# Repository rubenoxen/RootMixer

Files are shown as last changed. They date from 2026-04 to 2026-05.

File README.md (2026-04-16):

<p align="center">
  
  
  
  
</p>

# RootMixer 

A modular, bare-metal USB MIDI controller designed from scratch. Built around the STM32F411 (ARM Cortex-M4) using pure C CMSIS registers, featuring an expandable I2C and Analog Multiplexing architecture.

<p align="center">
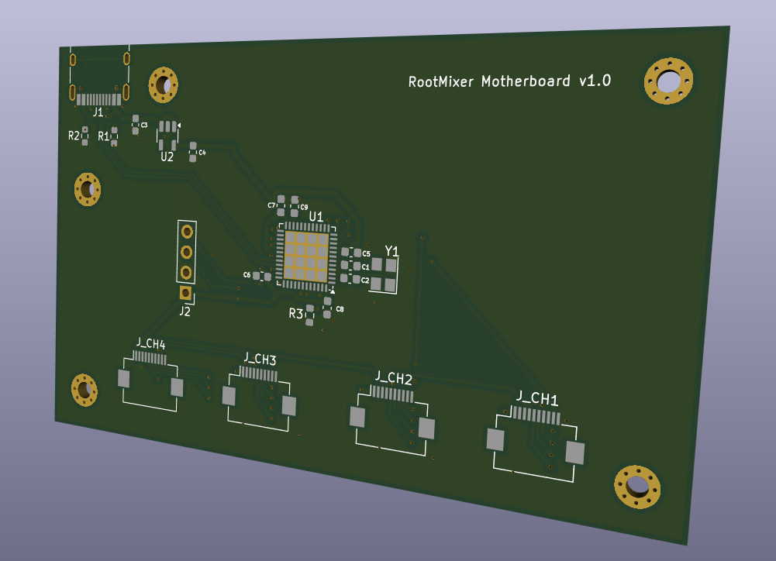
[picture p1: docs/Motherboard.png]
RootMixer 3D Render
  
</p>

##  Features
* **Bare-Metal Firmware:** Zero heavy libraries (No HAL, No Arduino). Direct register manipulation for ultra-low latency (<2ms scan rate).
* **Hardware Multiplexing:** Daisy-chained `CD74HC4067` multiplexers allowing up to 16 analog channels per ADC pin.
* **Modular Design:** 1 Motherboard supports up to 4 swappable Channel Strips.
* **Native USB MIDI:** Implemented custom USB Device stack to interface natively with DAWs (Ableton, FL Studio) without drivers.
* **Real-time OSless Scheduler:** Custom `SysTick` non-blocking architecture.

##  Project Structure
* `/firmware`: Pure C source code, Makefile, and linker scripts.
* `/hardware`: KiCad 7 projects, Schematics (PDF), and Gerber files ready for JLCPCB.
    * `/Motherboard`: Main STM32 brain, LDO power supply, and Expansion ports.
    * `/Daughterboard_Channel`: The swappable channel strip (1x SC6021N Fader, 4x WH148 Pots, Mute Button).

##  Build & Flash (Firmware)
Requires `arm-none-eabi-gcc`, `make`, and `openocd`.

```bash
cd firmware
make clean
make
make flash
```

## License
This project is licensed under the MIT License - see the LICENSE file for details.

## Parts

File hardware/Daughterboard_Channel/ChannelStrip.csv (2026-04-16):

Source: | /home/ruben/Workspace/RootMixer/hardware/Daughterboard_Channel/ChannelStrip/ChannelStrip.kicad_sch
Date: | jue 16 abr 2026 21:29:24
Tool: | Eeschema 7.0.11+dfsg-1build4
Generator: | /usr/share/kicad/plugins/bom_csv_grouped_by_value_with_fp.py
Component Count: | 13
Ref | Qnty | Value | Cmp name | Footprint | Description | Vendor | DNP
FADER1 | 1 | POT1 | R_Potentiometer | Potentiometer_THT:Potentiometer_Bourns_PTA6043_Single_Slide | Potentiometer
H1 | 1 | MountingHole | MountingHole | MountingHole:MountingHole_2.2mm_M2_Pad_Via | Mounting Hole without connection
H2, H3, H4 | 3 | MountingHole_Pad | MountingHole | MountingHole:MountingHole_2.2mm_M2_Pad_Via | Mounting Hole without connection
J1 | 1 | Conn_01x10 | Conn_01x10 | Connector_PinHeader_2.54mm:PinHeader_1x10_P2.54mm_Vertical | Generic connector, single row, 01x10, script generated (kicad-library-utils/schlib/autogen/connector/)
POT1, POT2, POT3, POT4 | 4 | POT1 | R_Potentiometer | Potentiometer_THT:Potentiometer_Bourns_PTV09A-1_Single_Vertical | Potentiometer
R1 | 1 | 10k | R | Resistor_THT:R_Axial_DIN0207_L6.3mm_D2.5mm_P10.16mm_Horizontal | Resistor
SW1 | 1 | SW_Push | SW_Push | Button_Switch_THT:SW_PUSH_6mm | Push button switch, generic, two pins
U1 | 1 | CD74HC4067M | CD74HC4067M | Package_SO:SOIC-24W_7.5x15.4mm_P1.27mm | High-Speed CMOS Logic 16-Channel Analog Multiplexer/Demultiplexer, SOIC-24

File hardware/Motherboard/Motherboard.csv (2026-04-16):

Source: | /home/ruben/Workspace/RootMixer/hardware/Motherboard/Motherboard/Motherboard.kicad_sch
Date: | jue 16 abr 2026 21:26:49
Tool: | Eeschema 7.0.11+dfsg-1build4
Generator: | /usr/share/kicad/plugins/bom_csv_grouped_by_value_with_fp.py
Component Count: | 26
Ref | Qnty | Value | Cmp name | Footprint | Description | Vendor | DNP
C1, C2 | 2 | 12pF | C_Small | Capacitor_SMD:C_0603_1608Metric | Unpolarized capacitor, small symbol
C3, C4 | 2 | 1uF | C_Small | Capacitor_SMD:C_0603_1608Metric | Unpolarized capacitor, small symbol
C5, C6, C7, C8 | 4 | 100nF | C_Small | Capacitor_SMD:C_0603_1608Metric | Unpolarized capacitor, small symbol
C9 | 1 | 4.7uF | C_Small | Capacitor_SMD:C_0603_1608Metric | Unpolarized capacitor, small symbol
H1, H2, H3, H4, H5 | 5 | MountingHole | MountingHole | MountingHole:MountingHole_2.2mm_M2_Pad_Via | Mounting Hole without connection
J1 | 1 | USB_C_Receptacle_USB2.0_16P | USB_C_Receptacle_USB2.0_16P | Connector_USB:USB_C_Receptacle_HRO_TYPE-C-31-M-12 | USB 2.0-only 16P Type-C Receptacle connector
J2 | 1 | Conn_01x04 | Conn_01x04 | Connector_PinHeader_2.54mm:PinHeader_1x04_P2.54mm_Vertical | Generic connector, single row, 01x04, script generated (kicad-library-utils/schlib/autogen/connector/)
J_CH1, J_CH2, J_CH3, J_CH4 | 4 | Conn_01x10 | Conn_01x10 | Connector_FFC-FPC:Hirose_FH12-10S-0.5SH_1x10-1MP_P0.50mm_Horizontal | Generic connector, single row, 01x10, script generated (kicad-library-utils/schlib/autogen/connector/)
R1, R2 | 2 | 5.1k | R | Resistor_SMD:R_0603_1608Metric | Resistor
R3 | 1 | 10k | R | Resistor_SMD:R_0603_1608Metric | Resistor
U1 | 1 | STM32F411CEUx | STM32F411CEUx | Package_DFN_QFN:QFN-48-1EP_7x7mm_P0.5mm_EP5.6x5.6mm | STMicroelectronics Arm Cortex-M4 MCU, 512KB flash, 128KB RAM, 100 MHz, 1.7-3.6V, 36 GPIO, UFQFPN48
U2 | 1 | AP2112K-3.3 | AP2112K-3.3 | Package_TO_SOT_SMD:SOT-23-5 | 600mA low dropout linear regulator, with enable pin, 3.8V-6V input voltage range, 3.3V fixed positive output, SOT-23-5
Y1 | 1 | 25MHz | Crystal_GND24 | Crystal:Crystal_SMD_3225-4Pin_3.2x2.5mm | Four pin crystal, GND on pins 2 and 4

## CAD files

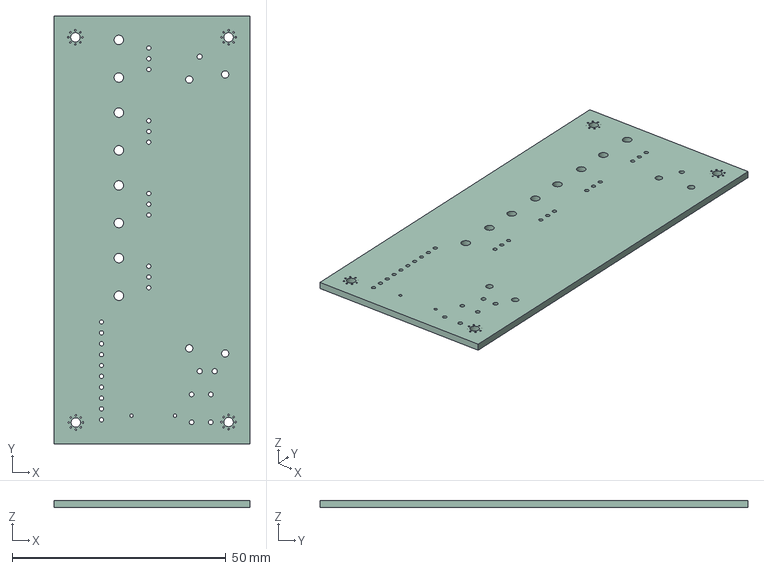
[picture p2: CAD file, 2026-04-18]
hardware/Daughterboard_Channel/ChannelStrip.step
45.8 x 100.0 x 1.60 mm

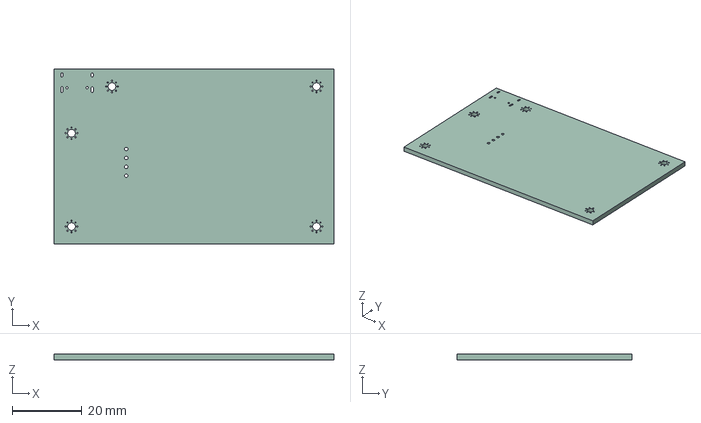
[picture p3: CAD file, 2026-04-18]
hardware/Motherboard/Motherboard.step
80.0 x 50.0 x 1.60 mm

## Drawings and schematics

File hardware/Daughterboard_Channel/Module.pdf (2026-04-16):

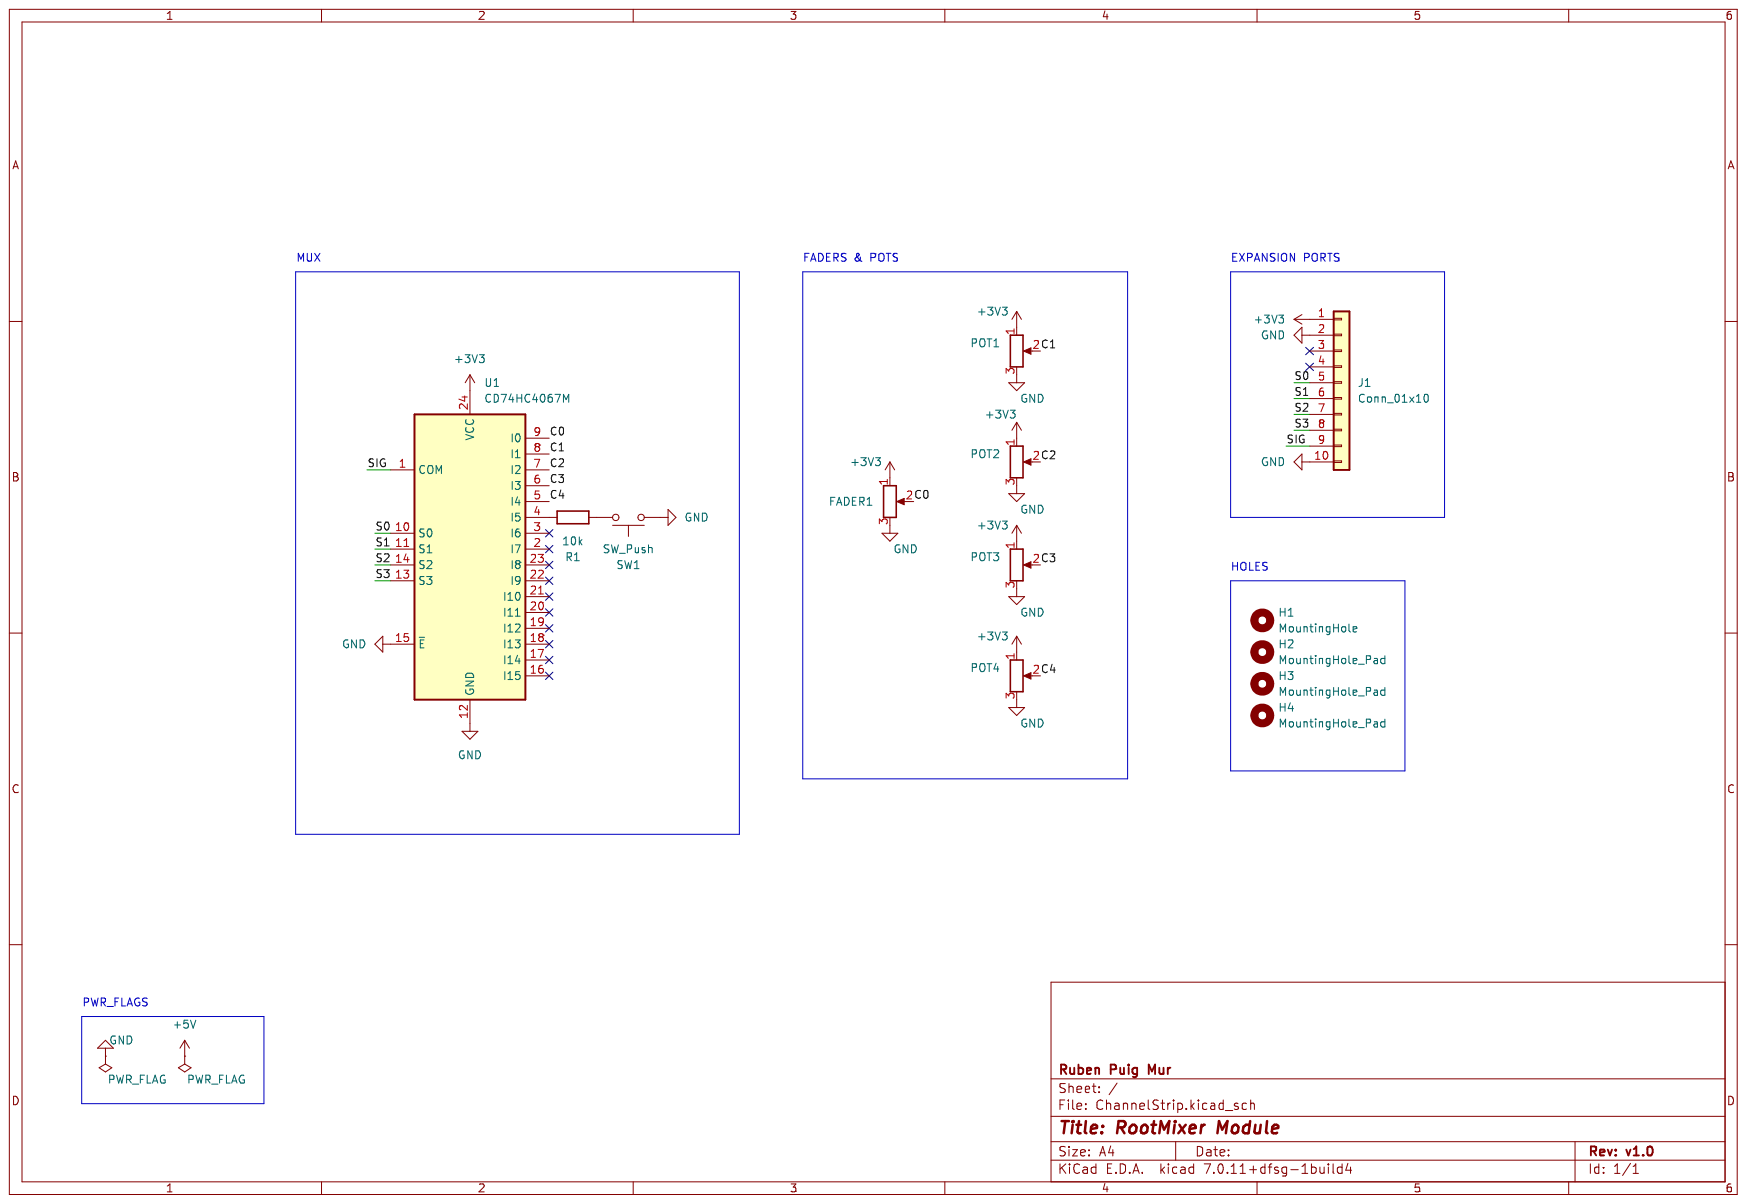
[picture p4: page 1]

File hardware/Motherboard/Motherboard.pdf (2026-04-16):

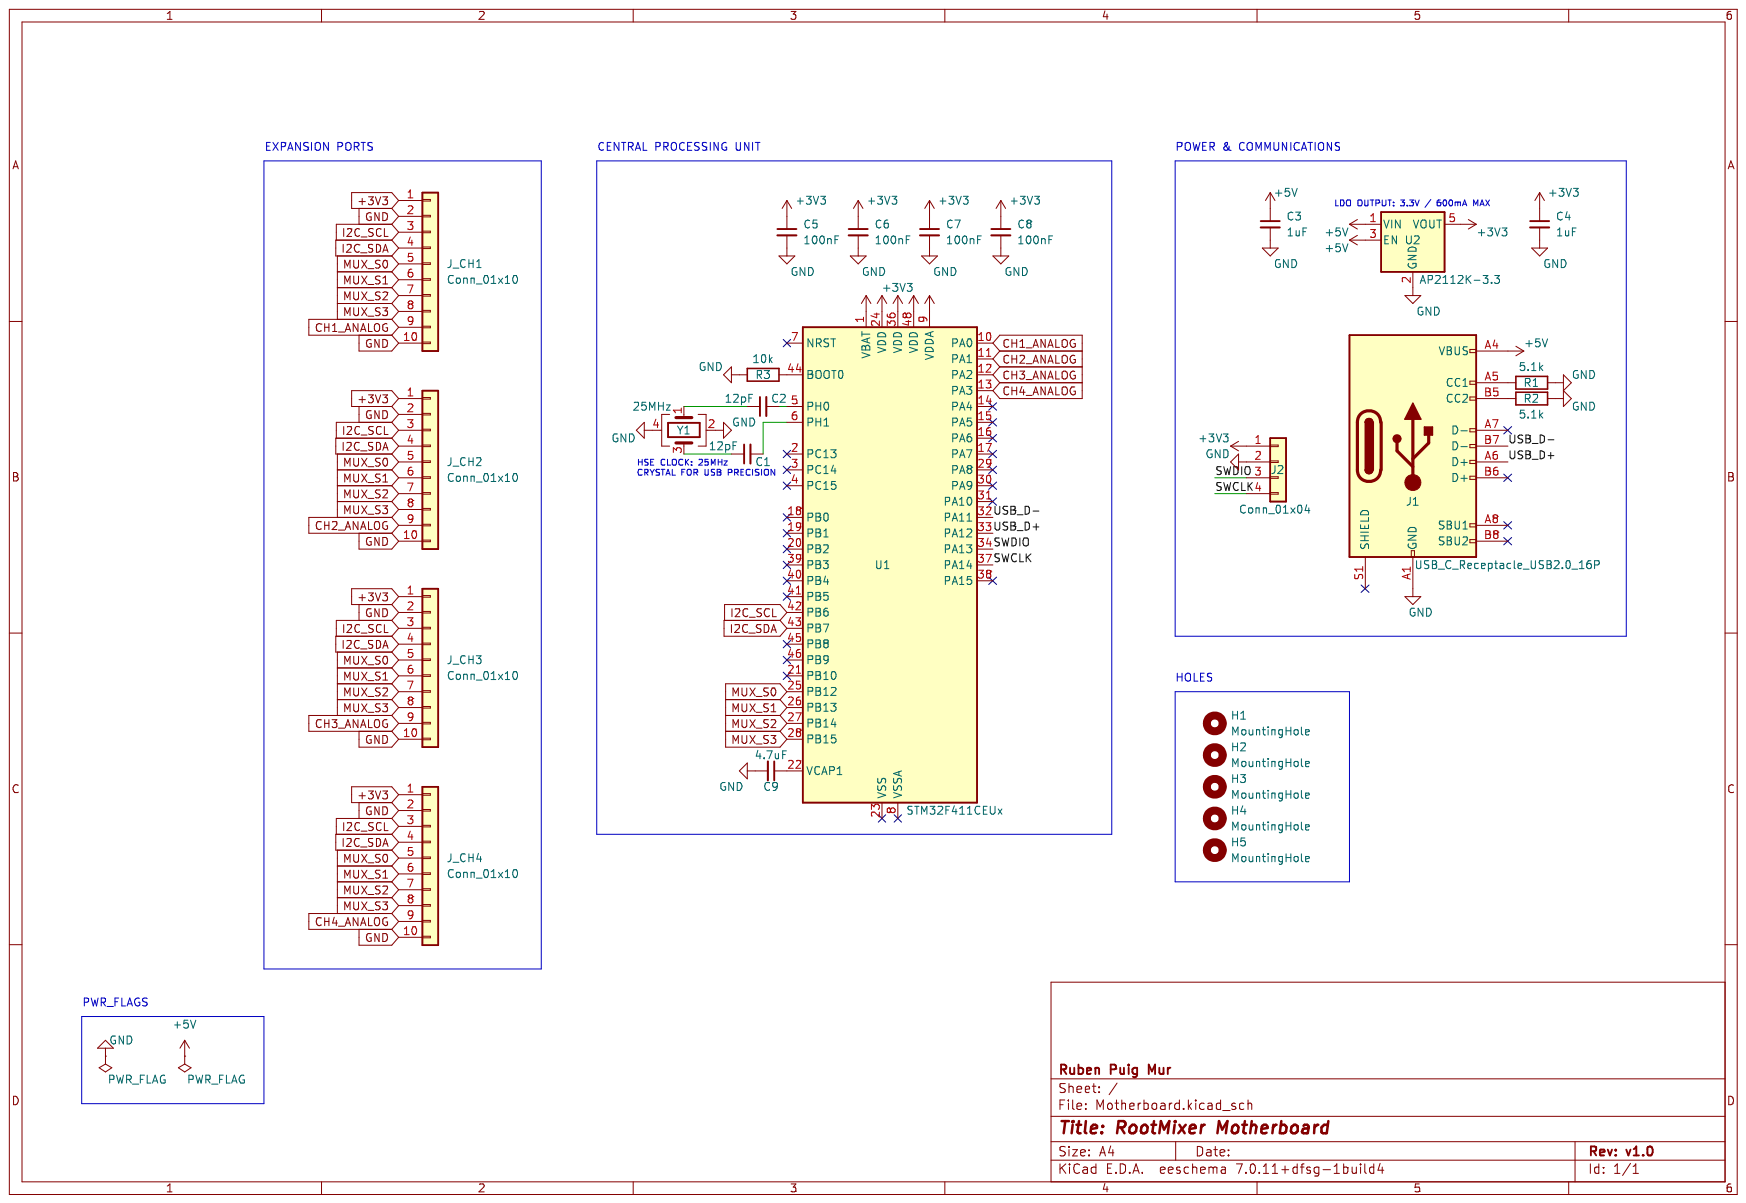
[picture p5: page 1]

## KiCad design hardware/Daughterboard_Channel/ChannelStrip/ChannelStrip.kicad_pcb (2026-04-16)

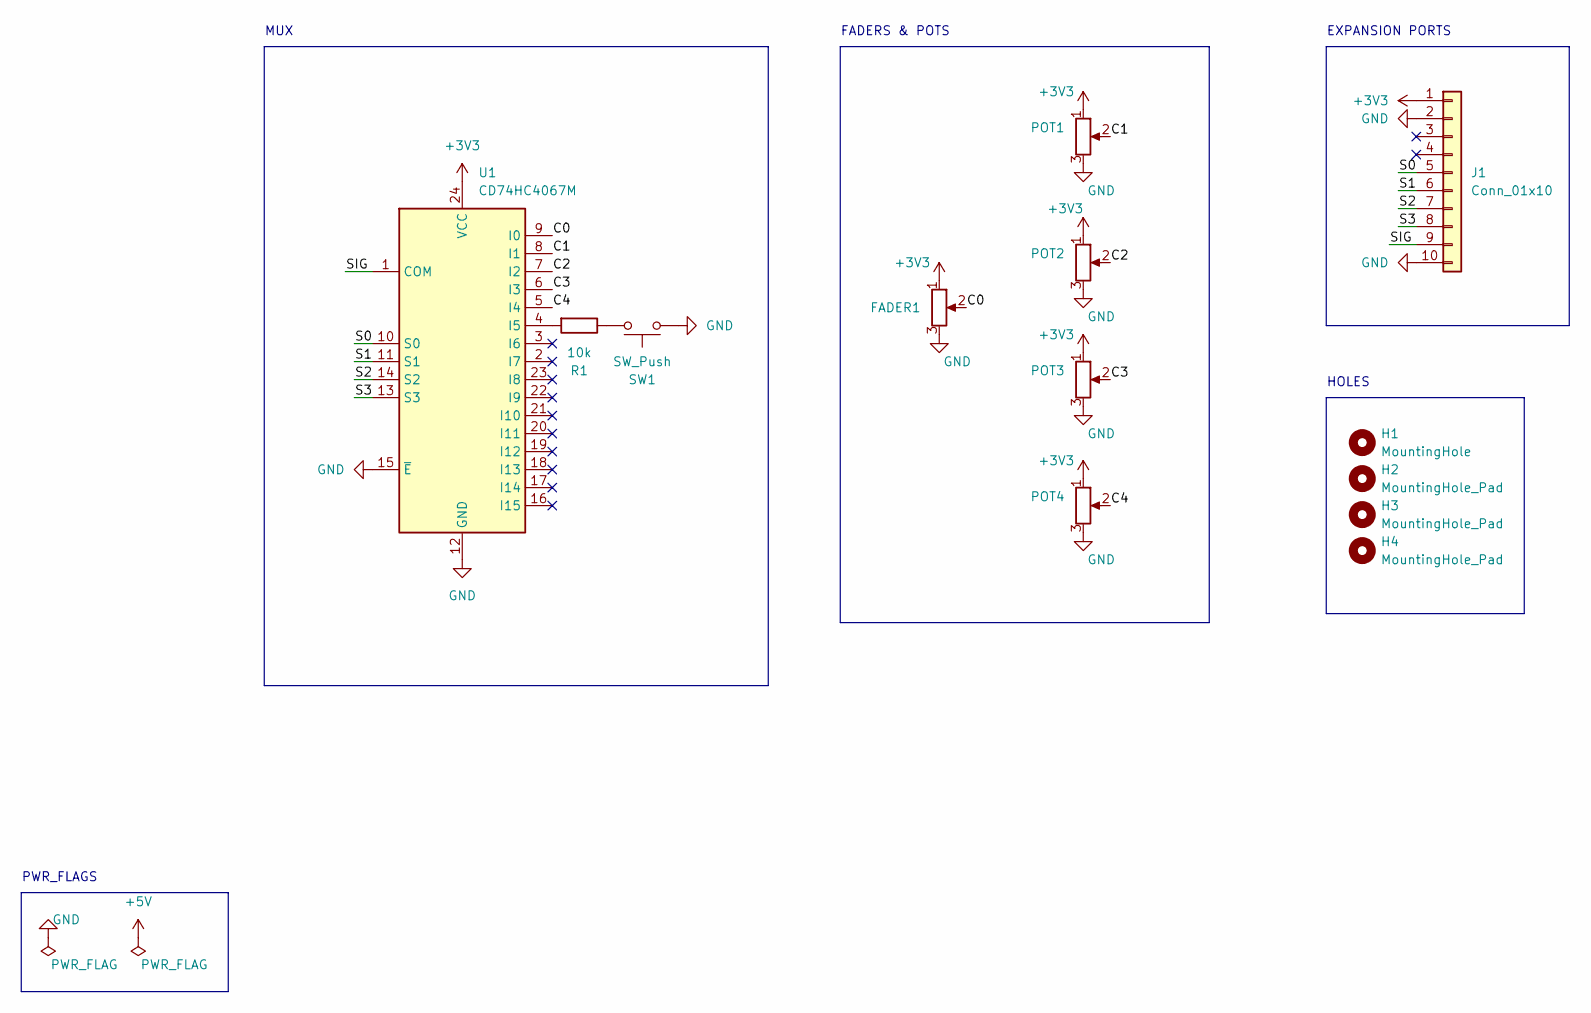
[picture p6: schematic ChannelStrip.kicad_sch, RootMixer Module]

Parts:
FADER1: POT1; Potentiometer_Bourns_PTA6043_Single_Slide
H1: MountingHole; MountingHole_2.2mm_M2_Pad_Via
H2, H3, H4: MountingHole_Pad; MountingHole_2.2mm_M2_Pad_Via
J1: Conn_01x10; PinHeader_1x10_P2.54mm_Vertical
POT1, POT2, POT3, POT4: POT1; Potentiometer_Bourns_PTV09A-1_Single_Vertical
R1: 10k; R_Axial_DIN0207_L6.3mm_D2.5mm_P10.16mm_Horizontal
SW1: SW_Push; SW_PUSH_6mm
U1: CD74HC4067M; SOIC-24W_7.5x15.4mm_P1.27mm

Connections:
+3V3: FADER1.1, J1.1, POT1.1, POT2.1, POT3.1, POT4.1, U1.24 (VCC)
/C0: FADER1.2, U1.9 (I0)
/C1: POT1.2, U1.8 (I1)
/C2: POT2.2, U1.7 (I2)
/C3: POT3.2, U1.6 (I3)
/C4: POT4.2, U1.5 (I4)
/S0: J1.5, U1.10 (S0)
/S1: J1.6, U1.11 (S1)
/S2: J1.7, U1.14 (S2)
/S3: J1.8, U1.13 (S3)
/SIG: J1.9, U1.1 (COM)
GND: FADER1.3, J1.2, J1.10, POT1.3, POT2.3, POT3.3, POT4.3, SW1.1, U1.12 (GND), U1.15 (~E)
unnamed: R1.1, SW1.2
unnamed: R1.2, U1.4 (I5)

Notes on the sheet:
FADERS & POTS
HOLES
PWR_FLAGS
EXPANSION PORTS
MUX

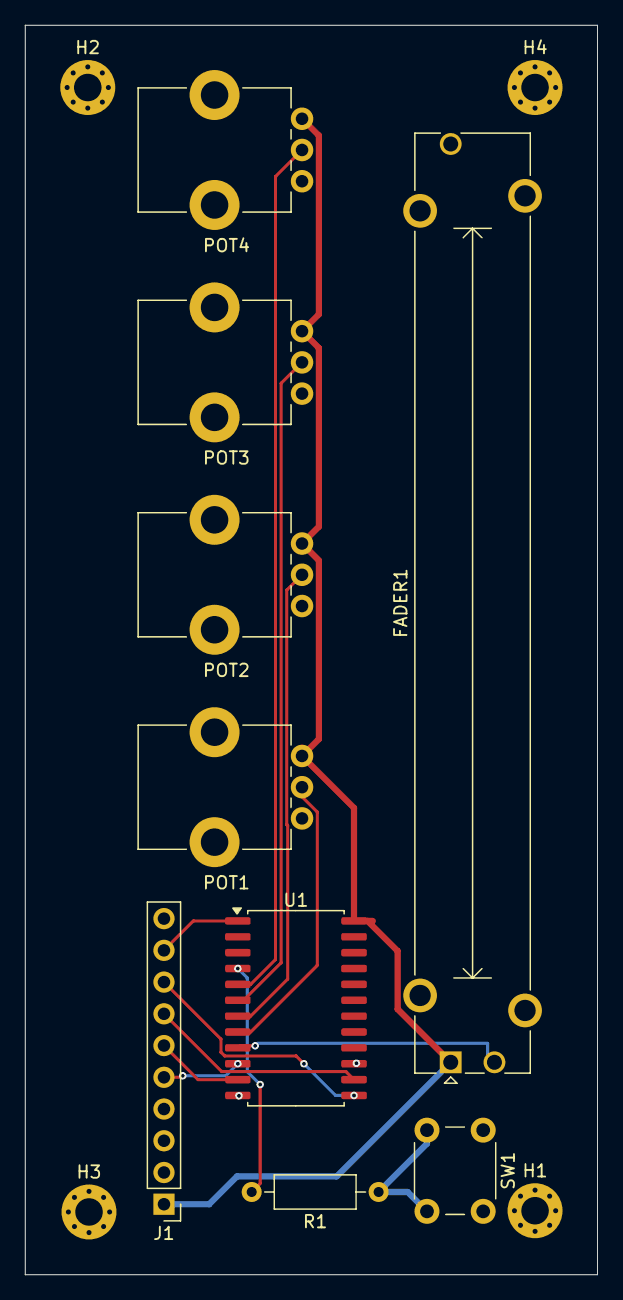
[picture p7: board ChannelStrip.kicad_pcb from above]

Board: 2 copper layers, 45.8 x 100.0 mm, 13 parts (0 on the bottom side), 14 nets.

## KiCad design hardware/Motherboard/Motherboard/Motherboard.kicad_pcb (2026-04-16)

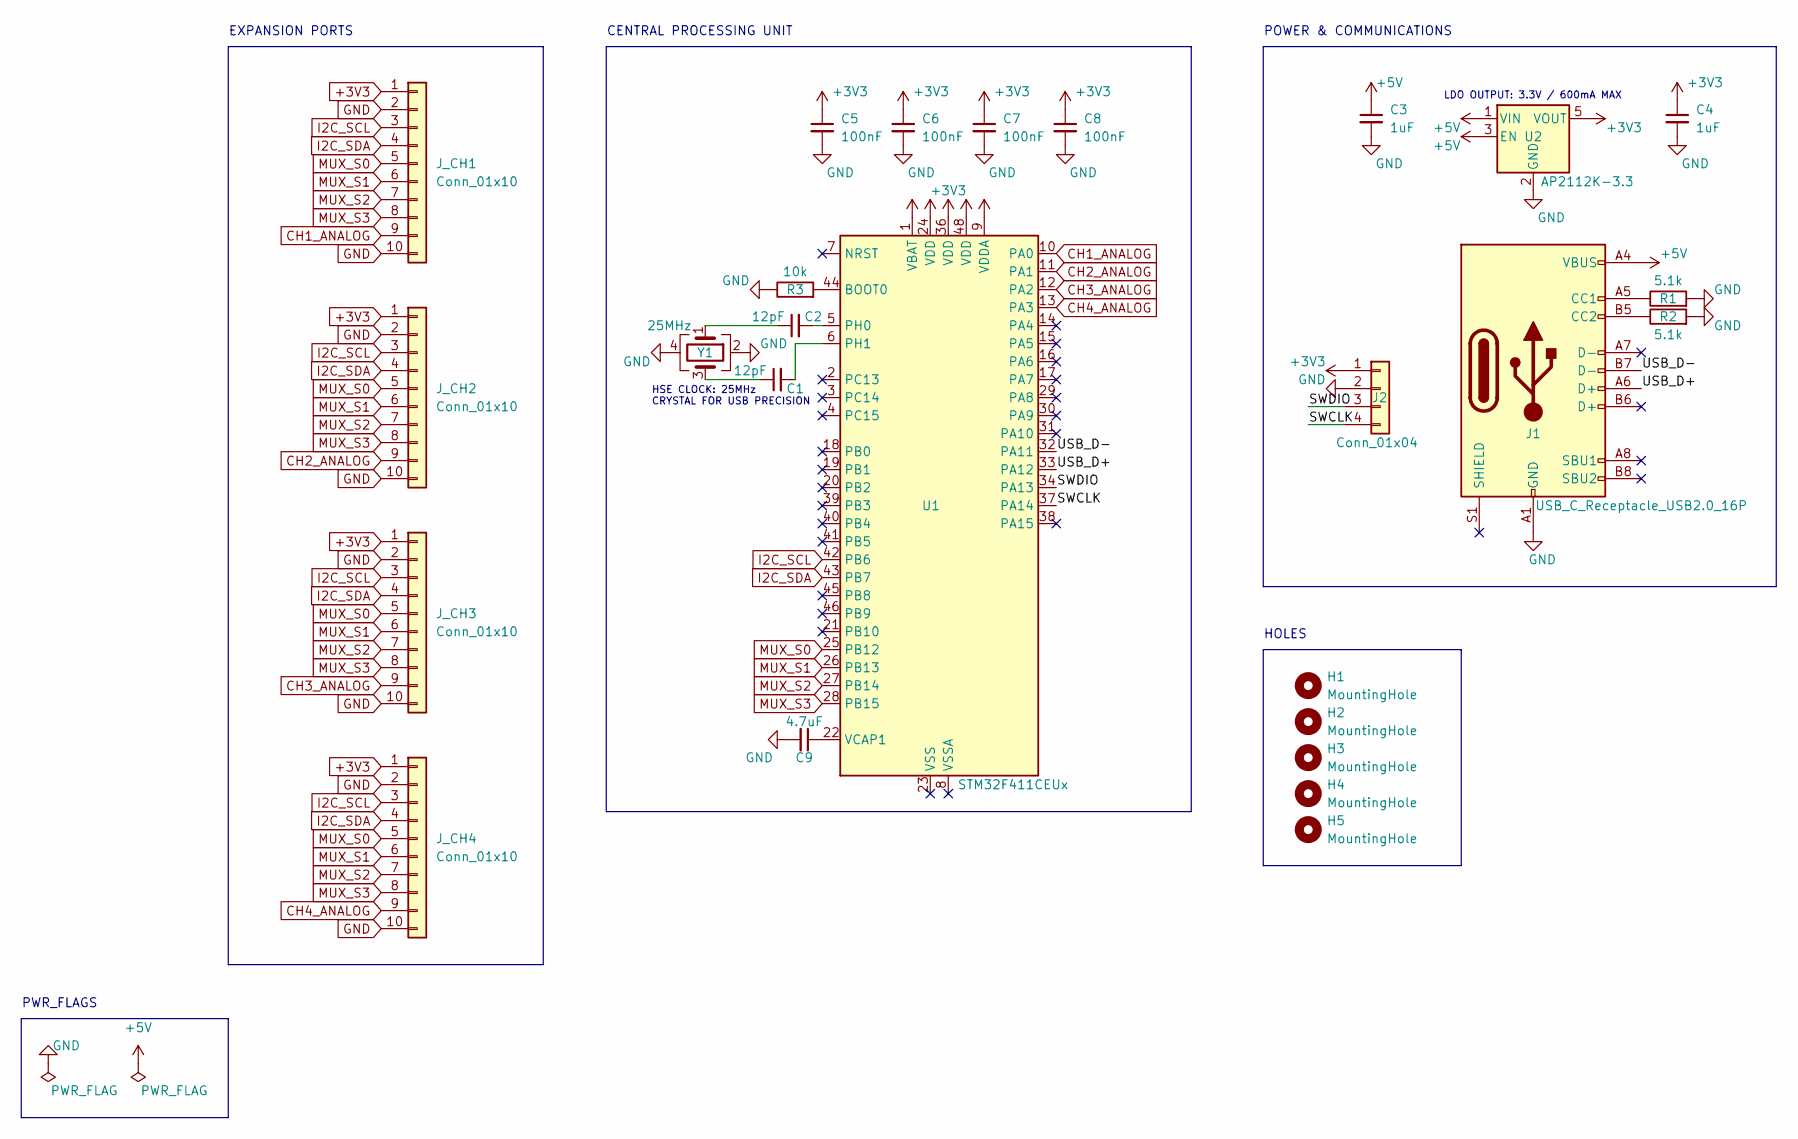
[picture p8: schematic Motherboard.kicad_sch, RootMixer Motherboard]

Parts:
C1, C2: 12pF; C_0603_1608Metric
C3, C4: 1uF; C_0603_1608Metric
C5, C6, C7, C8: 100nF; C_0603_1608Metric
C9: 4.7uF; C_0603_1608Metric
H1, H2, H3, H4, H5: MountingHole; MountingHole_2.2mm_M2_Pad_Via
J1: USB_C_Receptacle_USB2.0_16P; USB_C_Receptacle_HRO_TYPE-C-31-M-12
J2: Conn_01x04; PinHeader_1x04_P2.54mm_Vertical
J_CH1, J_CH2, J_CH3, J_CH4: Conn_01x10; Hirose_FH12-10S-0.5SH_1x10-1MP_P0.50mm_Horizontal
R1, R2: 5.1k; R_0603_1608Metric
R3: 10k; R_0603_1608Metric
U1: STM32F411CEUx; QFN-48-1EP_7x7mm_P0.5mm_EP5.6x5.6mm
U2: AP2112K-3.3; SOT-23-5
Y1: 25MHz; Crystal_SMD_3225-4Pin_3.2x2.5mm

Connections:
+3V3: C4.1, C5.1, C6.1, C7.1, C8.1, J2.1, J_CH1.1, J_CH2.1, J_CH3.1, J_CH4.1, U1.1 (VBAT), U1.9 (VDDA), U1.24 (VDD), U1.36 (VDD), U1.48 (VDD), U2.5 (VOUT)
+5V: C3.1, J1.A4 (VBUS), J1.A9 (VBUS), J1.B4 (VBUS), J1.B9 (VBUS), U2.1 (VIN), U2.3 (EN)
/SWCLK: J2.4, U1.37 (PA14)
/SWDIO: J2.3, U1.34 (PA13)
/USB_D+: J1.A6 (D+), U1.33 (PA12)
/USB_D-: J1.B7 (D-), U1.32 (PA11)
CH1_ANALOG: J_CH1.9, U1.10 (PA0)
CH2_ANALOG: J_CH2.9, U1.11 (PA1)
CH3_ANALOG: J_CH3.9, U1.12 (PA2)
CH4_ANALOG: J_CH4.9, U1.13 (PA3)
GND: C3.2, C4.2, C5.2, C6.2, C7.2, C8.2, C9.2, J1.A1 (GND), J1.A12 (GND), J1.B1 (GND), J1.B12 (GND), J2.2, J_CH1.2, J_CH1.10, J_CH2.2, J_CH2.10, J_CH3.2, J_CH3.10, J_CH4.2, J_CH4.10, R1.2, R2.2, R3.1, U2.2 (GND), Y1.2, Y1.4
I2C_SCL: J_CH1.3, J_CH2.3, J_CH3.3, J_CH4.3, U1.42 (PB6)
I2C_SDA: J_CH1.4, J_CH2.4, J_CH3.4, J_CH4.4, U1.43 (PB7)
MUX_S0: J_CH1.5, J_CH2.5, J_CH3.5, J_CH4.5, U1.25 (PB12)
MUX_S1: J_CH1.6, J_CH2.6, J_CH3.6, J_CH4.6, U1.26 (PB13)
MUX_S2: J_CH1.7, J_CH2.7, J_CH3.7, J_CH4.7, U1.27 (PB14)
MUX_S3: J_CH1.8, J_CH2.8, J_CH3.8, J_CH4.8, U1.28 (PB15)
unnamed: C1.1, Y1.3
unnamed: C2.1, Y1.1
unnamed: J1.A5 (CC1), R1.1
unnamed: J1.B5 (CC2), R2.1
unnamed: R3.2, U1.44 (BOOT0)
unnamed: C2.2, U1.5 (PH0)
unnamed: C1.2, U1.6 (PH1)
unnamed: C9.1, U1.22 (VCAP1)

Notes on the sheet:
HSE CLOCK: 25MHz CRYSTAL FOR USB PRECISION
LDO OUTPUT: 3.3V / 600mA MAX
EXPANSION PORTS
POWER & COMMUNICATIONS
HOLES
CENTRAL PROCESSING UNIT
PWR_FLAGS

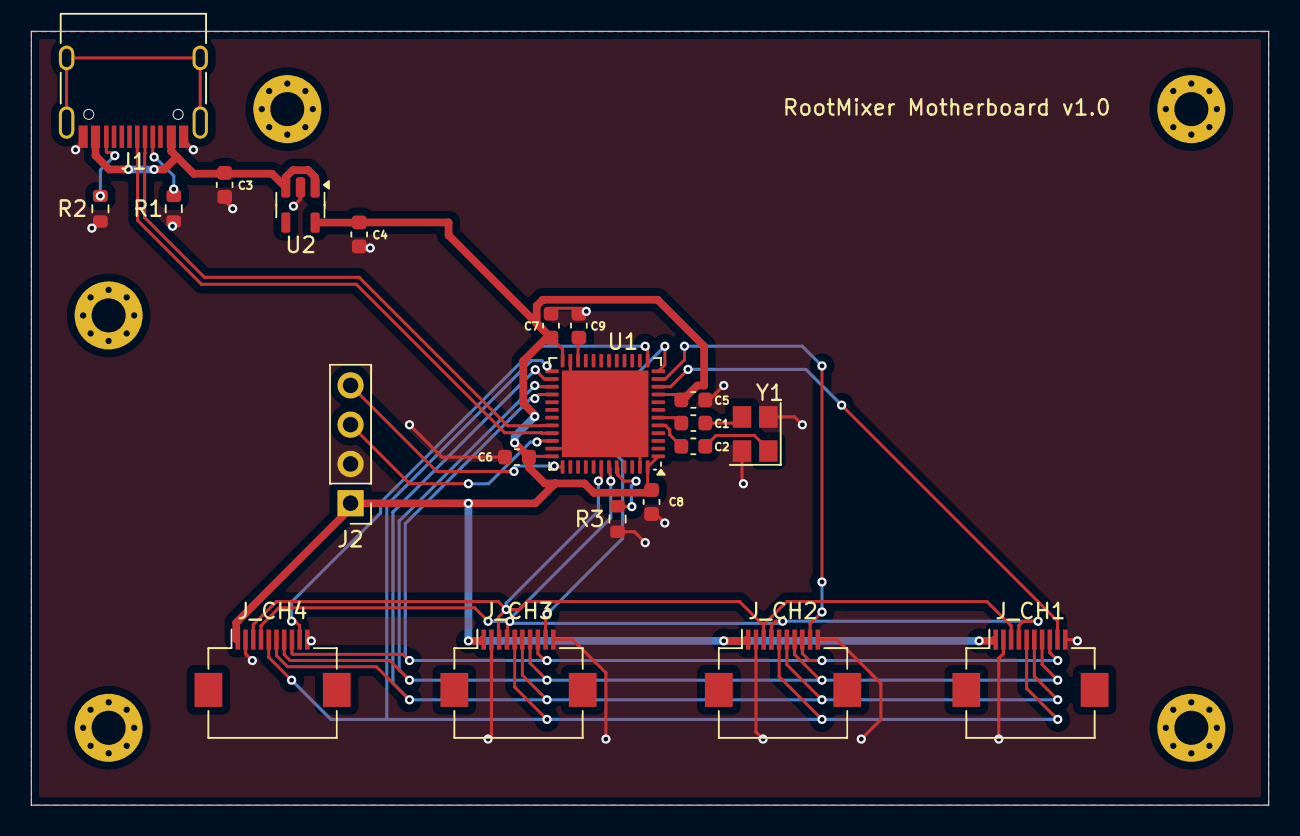
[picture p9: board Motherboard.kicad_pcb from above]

Board: 2 copper layers, 80.0 x 50.0 mm, 26 parts (0 on the bottom side), 25 nets.

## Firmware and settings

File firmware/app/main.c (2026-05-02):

#include "stm32f411.h"
#include "systick.h"
#include "tusb.h"
#include "buttons.h"
#include <stdbool.h>
#include <stddef.h>

// --- DEPENDENCIAS DEL ENLAZADOR ---
uint32_t SystemCoreClock = 96000000;
uint32_t board_millis(void) { return Get_Millis(); }
uint32_t tusb_time_millis_api(void) { return Get_Millis(); }
void *memcpy(void *dest, const void *src, size_t n) {
    uint8_t *d = (uint8_t *)dest; const uint8_t *s = (const uint8_t *)src;
    while (n--) *d++ = *s++; return dest;
}
void *memset(void *s, int c, size_t n) {
    uint8_t *p = (uint8_t *)s;
    while (n--) *p++ = (uint8_t)c; return s;
}
size_t strlen(const char *s) {
    const char *p = s; while (*p) p++; return p - s;
}

// --- CONFIGURACIÓN DE RELOJES ---
void SystemClock_Config(void) {
    RCC_CR |= 1; while (!(RCC_CR & 2)); 
    RCC_CFGR = 0; 
    FLASH_ACR = (1 << 8) | (1 << 9) | (1 << 10) | (3 << 0);
    RCC_PLLCFGR = (4 << 24) | (0 << 22) | (0 << 16) | (192 << 6) | 16;
    RCC_CR |= (1 << 24); while (!(RCC_CR & (1 << 25)));
    RCC_CFGR = (4 << 10) | 2; while ((RCC_CFGR & (3 << 2)) != (2 << 2));
}

// --- INICIALIZACIÓN HARDWARE USB ---
void USB_Hardware_Init(void) {
    RCC_AHB1ENR |= (1 << 0); 
    RCC_AHB2ENR |= (1 << 7); 
    GPIOA_MODER = (GPIOA_MODER & ~(0xF << 22)) | (0xA << 22);
    GPIOA_AFRH = (GPIOA_AFRH & ~(0xFF << 12)) | (0xAA << 12);
    GPIOA_OSPEEDR |= (0xF << 22);
    NVIC_ISER2 |= (1 << 3); 
}
void OTG_FS_IRQHandler(void) { tud_int_handler(0); }

// --- MAIN ---
int main(void) {
    SystemClock_Config();
    SysTick_Init();
    Buttons_Init();

    // LED de control (PC13)
    RCC_AHB1ENR |= (1 << 2); 
    GPIOC_MODER = (GPIOC_MODER & ~(3 << 26)) | (1 << 26); 

    USB_Hardware_Init();
    tusb_init(); 

    uint32_t last_blink = Get_Millis();
    bool led_on = false;

    // Variables para controlar el estado del botón sin bloquear el código
    bool last_btn_state = false;
    uint32_t last_btn_time = 0;

    while (1) {
        // 1. Mantener vivo el protocolo USB (VITAL)
        tud_task(); 

        // 2. Parpadeo de supervivencia del LED (cada 500ms)
        if (Get_Millis() - last_blink >= 500) {
            last_blink = Get_Millis();
            if (led_on) GPIOC_BSRR = (1 << 29); 
            else GPIOC_BSRR = (1 << 13); 
            led_on = !led_on;
        }

        // 3. Leer el botón con debounce de 50ms
        if (Get_Millis() - last_btn_time >= 50) {
            bool current_btn_state = Button_Is_Pressed();
            
            // Si el estado ha cambiado
            if (current_btn_state != last_btn_state) {
                last_btn_state = current_btn_state;
                last_btn_time = Get_Millis();
                
                // Si la conexión USB está lista para enviar datos
                if (tud_midi_mounted()) {
                    uint8_t midi_msg[3];
                    if (current_btn_state) {
                        // Botón pulsado: Enviar Note ON (Canal 1, Nota 60/C4, Velocidad 127)
                        midi_msg[0] = 0x90; 
                        midi_msg[1] = 60;   
                        midi_msg[2] = 127;  
                    } else {
                        // Botón soltado: Enviar Note OFF (Canal 1, Nota 60/C4, Velocidad 0)
                        midi_msg[0] = 0x80; 
                        midi_msg[1] = 60;   
                        midi_msg[2] = 0;    
                    }
                    // Enviar los 3 bytes al cable
                    tud_midi_stream_write(0, midi_msg, 3);
                }
            }
        }
    }
}

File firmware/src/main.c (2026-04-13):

#include <stdint.h>
#include "stm32f411.h"
#include "systick.h"
#include "i2c.h"
#include "ssd1306.h"
#include "buttons.h"

// Variables de Estado de la App
uint8_t fader_state[4] = {0};
uint8_t button_state = 0;
uint8_t ui_dirty = 1;

void Mixer_App_Init(void) {
    SystemClock_Config();
    SysTick_Init();
    USB_GPIO_Init();
    USB_Core_Init();
    USB_NVIC_Init();
    USB_Device_Init();
    ADC_Init();
    Buttons_Init();
    I2C_Init();
    SSD1306_Init();
}

void Draw_Master_UI(void) {
    SSD1306_Clear();
    for (uint8_t i = 0; i < 4; i++) {
        uint8_t bar_h = (fader_state[i] * 50) / 127;
        uint8_t x_pos = (i * 30) + 5;
        SSD1306_DrawFilledRect(x_pos, 50 - bar_h, 20, bar_h, 1);

        if (button_state & (1 << i)) {
            SSD1306_DrawFilledRect(x_pos + 5, 54, 10, 10, 1);
        }
    }
    SSD1306_UpdateScreen();
}

int main(void) {
    Mixer_App_Init();

    uint8_t cc_faders[4] = {7, 8, 9, 10};
    uint8_t cc_buttons[4] = {20, 21, 22, 23};
    uint8_t last_faders[4] = {255, 255, 255, 255};
    uint8_t last_buttons = 255;

    // Controladores de tiempo (Time tracking)
    uint32_t last_scan_time = 0;
    uint32_t last_ui_time = 0;

    while (1) {
        uint32_t current_time = Get_Millis();

        // TAREA 1: Escanear Hardware (1000 veces por segundo / 1ms)
        if (current_time - last_scan_time >= 1) {
            last_scan_time = current_time;

            // Escáner ADC
            for (uint8_t i = 0; i < 4; i++) {
                uint8_t val = (ADC_Read(i) >> 5);
                if (val != last_faders[i]) {
                    USB_Send_MIDI_CC(cc_faders[i], val);
                    fader_state[i] = val;
                    last_faders[i] = val;
                    ui_dirty = 1;
                }
            }

            // Escáner Digital
            uint8_t current_btn = Buttons_Read();
            if (current_btn != last_buttons) {
                for (uint8_t i = 0; i < 4; i++) {
                    uint8_t was_pressed = (last_buttons & (1 << i));
                    uint8_t is_pressed = (current_btn & (1 << i));

                    if (is_pressed && !was_pressed) {
                        USB_Send_MIDI_CC(cc_buttons[i], 127);
                    } else if (!is_pressed && was_pressed) {
                        USB_Send_MIDI_CC(cc_buttons[i], 0);
                    }
                }
                button_state = current_btn;
                last_buttons = current_btn;
                ui_dirty = 1;
            }
        }

        // TAREA 2: Refresco de Pantalla (Max 30 FPS / 33ms)
        if ((current_time - last_ui_time >= 33) && ui_dirty) {
            last_ui_time = current_time;
            Draw_Master_UI();
            ui_dirty = 0;
        }
    }
}

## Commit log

2026-04-16 Release v1.0: Hardware Schematics, BOM, Bare-Metal Firmware and MIT License
2026-05-02 hemos llegado a lo fisico, se jodio la marrana

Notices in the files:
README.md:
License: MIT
